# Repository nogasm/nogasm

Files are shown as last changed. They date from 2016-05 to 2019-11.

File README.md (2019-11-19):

# nogasm
Software and hardware for Arduino-based orgasm prediction / detection

### Case
The case can be 3D printed without support material. Print at least the top half of the case in white to see the LED display beneath. 

### PCB
All the Gerber files are included to order a set of PCBs. The [BOM is available on Octopart](https://octopart.com/bom-tool/FGy3gDRv). The PCB has mostly surface-mount components, and is doable with either a soldering iron or solder paste.

### Vibrator
The vibrator is made from a Mabuchi RS-555PH motor, with an eccentric mass pressed onto the shaft. These can be purchased pre-assembled, or built from the motor and some .88" to 1" diameter cylindrical brass stock.
The vibrator case is compatible with attachments designed for the Hitachi Magic Wand. The motor is press-fit or glued into the two halves of the case.

### Dependencies
This project uses a [Teensy LC](https://www.pjrc.com/store/teensylc.html), which will require the [teensyduino](https://www.pjrc.com/teensy/teensyduino.html) addon for the Arduino IDE, and its included [encoder library](https://github.com/PaulStoffregen/Encoder).
The detection algorithm uses a circular buffer for calculating a running average, [available here](https://github.com/RobTillaart/Arduino/tree/master/libraries/RunningAverage).

This work is licensed under a Creative Commons Attribution-NonCommercial 4.0 International Licence, available at http://creativecommons.org/licenses/by-nc/4.0/.

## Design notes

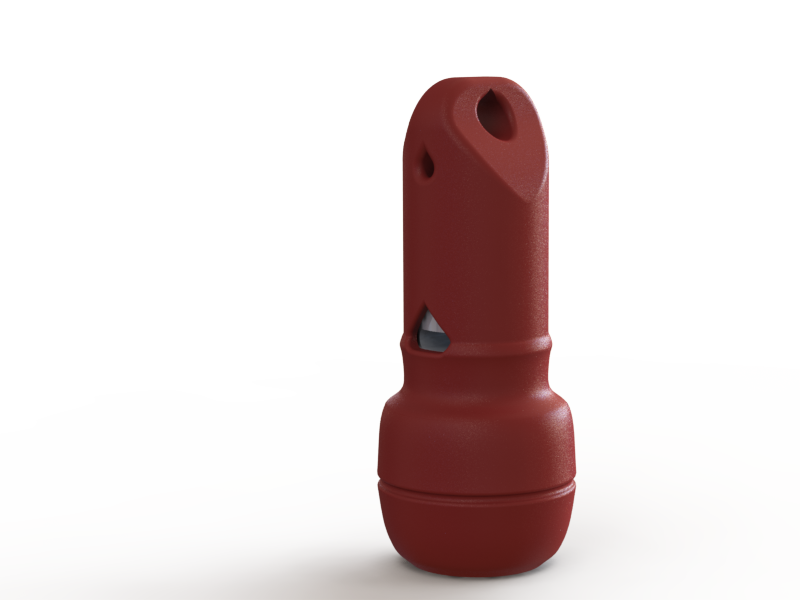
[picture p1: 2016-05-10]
vibrator/vibrator.png

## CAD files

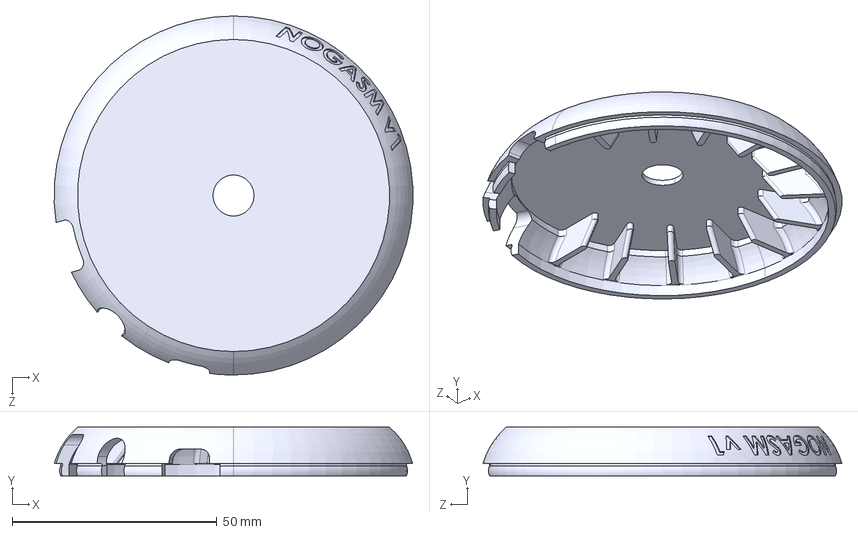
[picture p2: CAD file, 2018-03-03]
case/CaseUpper.STEP
87.5 x 11.9 x 87.6 mm

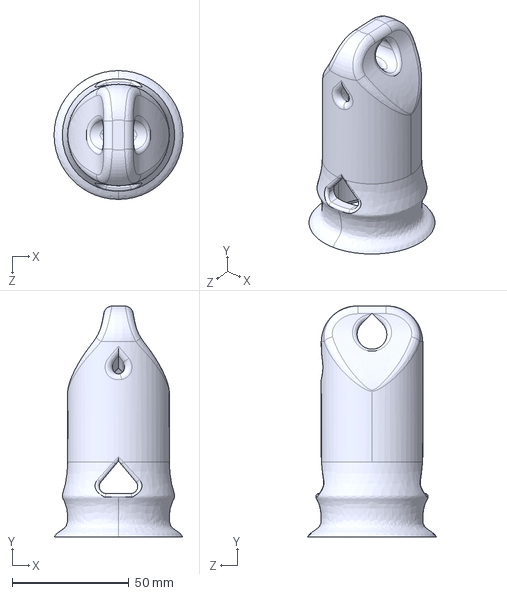
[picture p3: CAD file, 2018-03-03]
vibrator/handle.STEP
55.3 x 99.1 x 55.3 mm

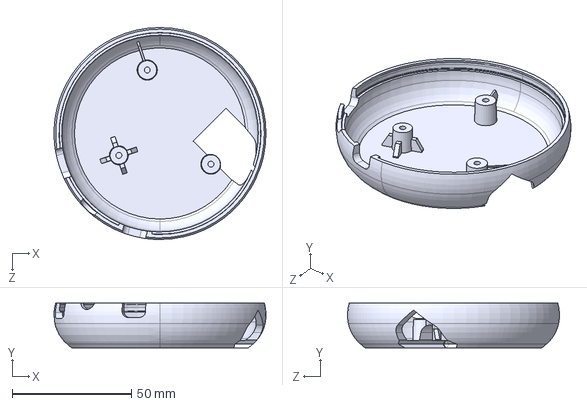
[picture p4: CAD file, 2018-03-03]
case/CaseLower.STEP
89.0 x 18.9 x 89.0 mm

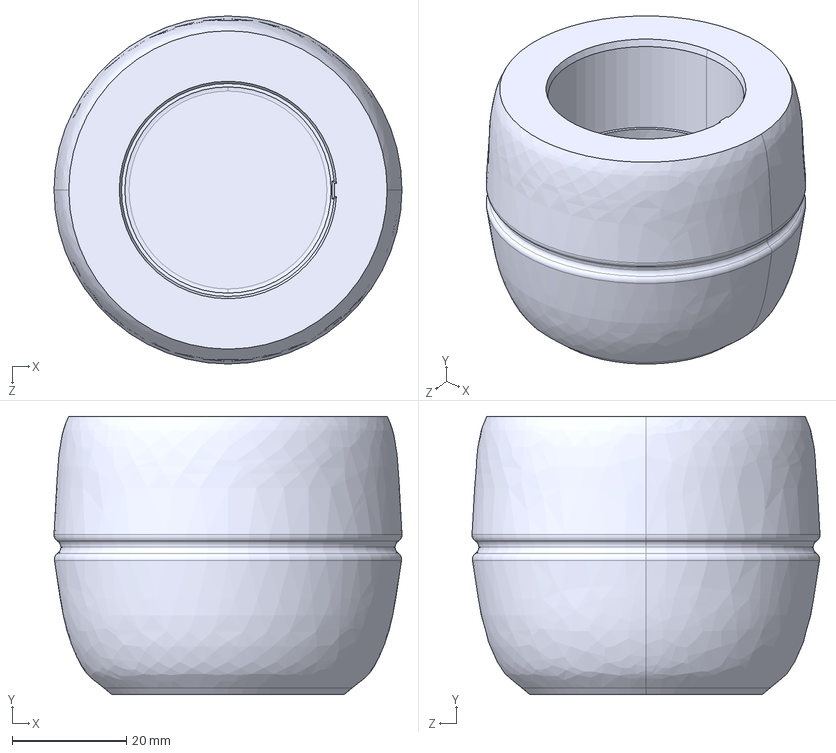
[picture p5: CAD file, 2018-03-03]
vibrator/head.STEP
60.8 x 48.6 x 60.8 mm

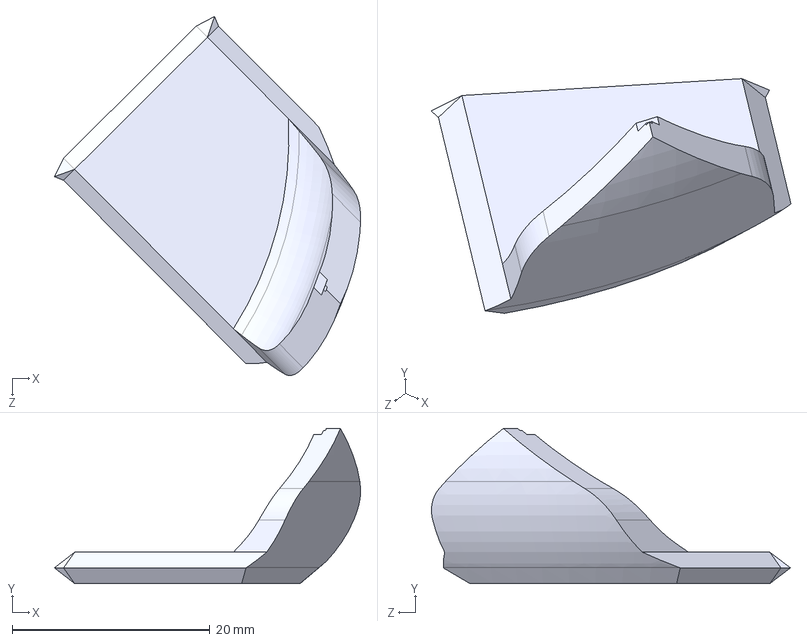
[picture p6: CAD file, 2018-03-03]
case/CaseProgramLid.STEP
31.0 x 15.7 x 36.3 mm

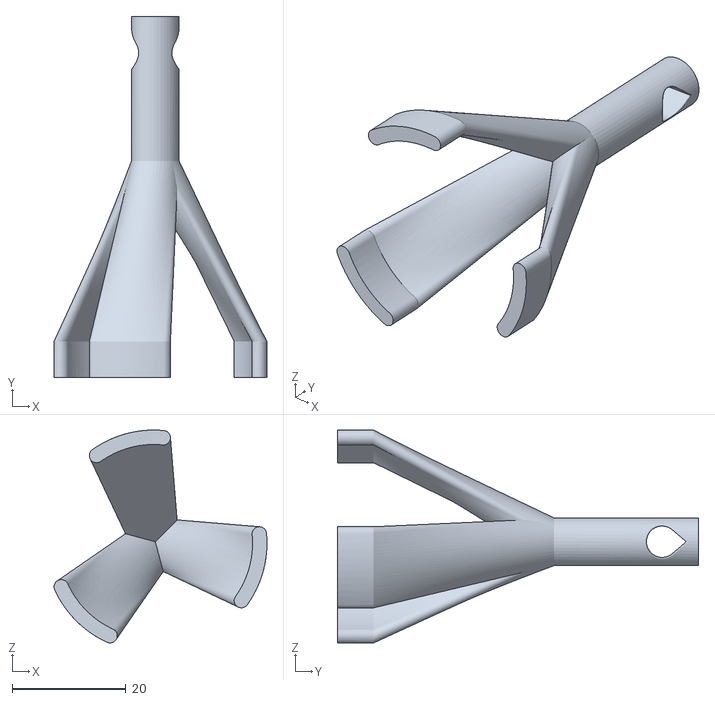
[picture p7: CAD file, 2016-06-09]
vibrator/finishing jig.STL
37.5 x 63.5 x 37.5

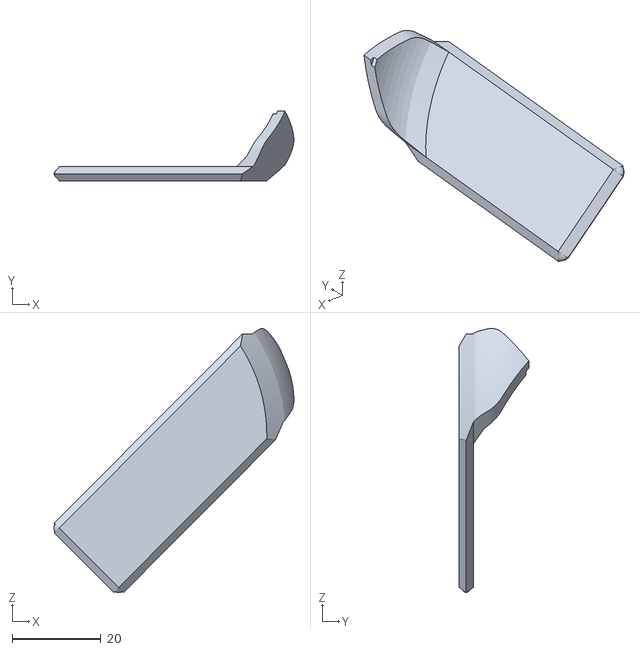
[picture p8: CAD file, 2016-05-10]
case/CaseLid.STL
54.1 x 15.7 x 59.6

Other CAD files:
case/CaseLower.STL
case/CaseUpper.STL
vibrator/handle.STL
vibrator/head.STL

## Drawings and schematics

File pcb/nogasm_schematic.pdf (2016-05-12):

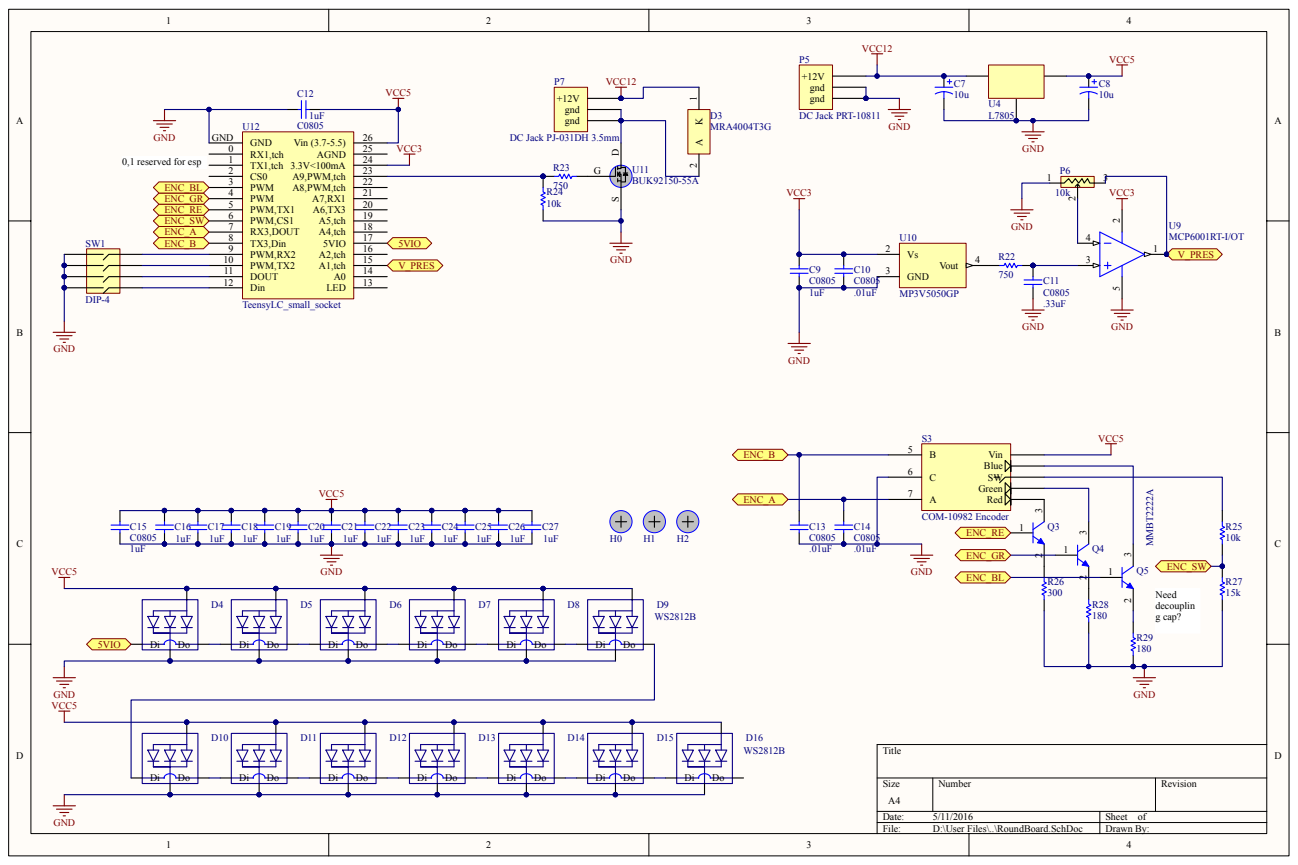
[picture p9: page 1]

Size A4 | Number | Revision

Date: 5/11/2016 | Sheet of
File: D:\User Files\..\RoundBoard.SchDoc | Drawn By:

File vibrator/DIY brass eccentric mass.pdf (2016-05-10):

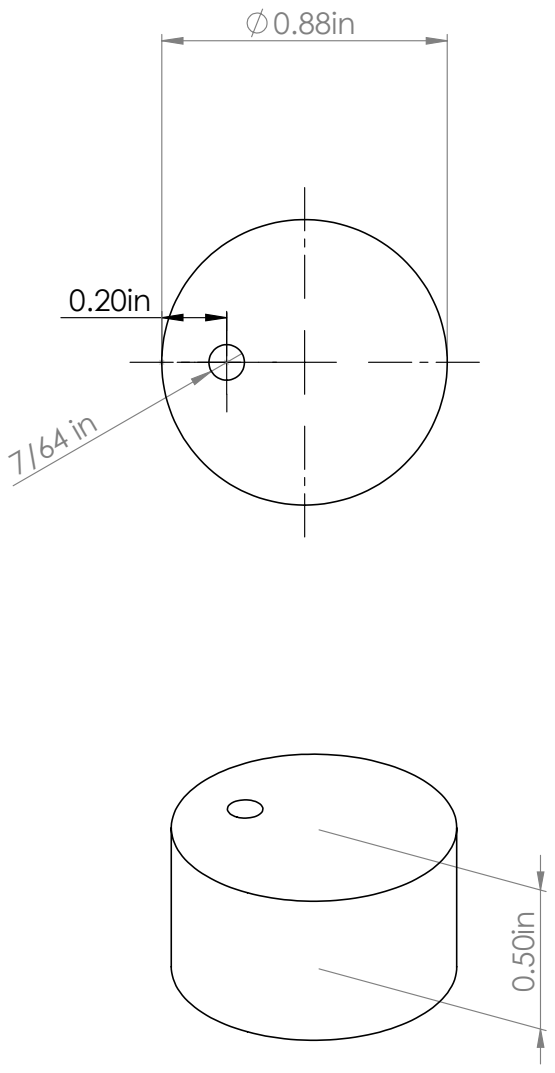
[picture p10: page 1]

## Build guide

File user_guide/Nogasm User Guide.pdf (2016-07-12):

## Nogasm User Guide

Basic Usage

1. Plug the motor into the right power jack.
2. Plug the power supply into the left power jack.
3. Fit the pressure tubing onto the barb fitting between the power jacks.
4. Connect an inflation bulb and inflatable butt plug to the pressure tubing as shown:

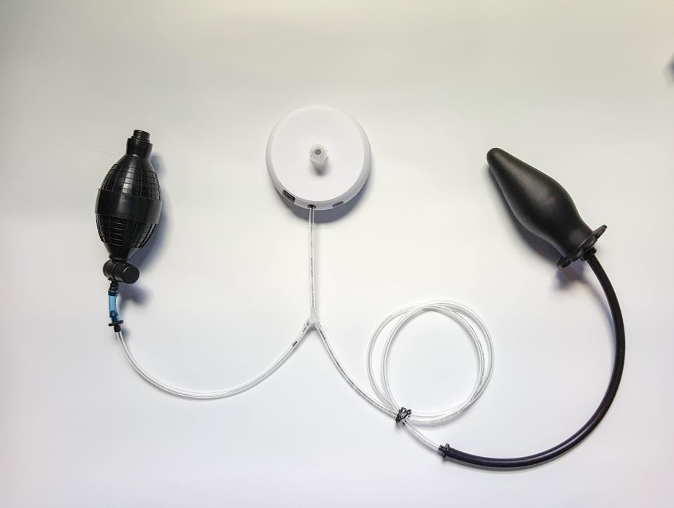
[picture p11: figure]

5. Nogasm detects approaching orgasms from pressure changes in an inflatable butt plug, so to use the edging feature, a user has to wear an at least slightly inflated plug.
6. Set up the vibrator for effective stimulation. Any common “Hitachi Magic Wand” attachment is compatible. If using rope to hold the vibrator in place, the loop in the back, and ridge behind the head of the vibrator can help keep it secure.
7. With the Nogasm on, turn the knob clockwise to check that the vibrator is working. Voluntarily clenching on the inflated plug should show some activity on the LED display at this point.
8. Press the knob once to enable the automated edging mode. The vibrator will slowly ramp up to its maximum speed.
9. The biggest key to a successful edging session is the edging sensitivity setting. Turn the knob clockwise to increase the sensitivity to maximum, and the display will turn from green to red, indicating that the user is too close to orgasm, and the vibrator will turn off temporarily.

10.From there, decrease the sensitivity slowly until you find the correct setting where the vibrator remains on just until the user is close to orgasm. Too high of a sensitivity will keep users from getting very close to orgasm at all, and too low of a sensitivity will allow the vibrator to stay on long enough for a user to cum. Ideal settings vary from person to person, and with different styles of inflatable plugs. If at any point a user is too close to orgasm, the knob can be pressed to immediately turn off the vibrator, and return to manual mode.
11.Finally, the included vibrator is relatively powerful, and lower speeds can feel better than 100% speed. To keep the vibrator at the best feeling speed in automatic mode, press the knob down for 1 second to enter the “Peak Speed” settings menu, which will change the display to all green. Rotating the knob will adjust the maximum speed that the edging mode will ramp up to, and drive the vibrator at that speed to demonstrate. By default, the maximum is set 70%. Long press one more time to return to manual mode.

Control

The Nogasm has one knob that can be rotated or pressed. Pressing the knob will change modes. Each mode illuminates the knob in a specific color, and uses the knob rotation to adjust different settings:

Mode | Knob Color | Knob rotation adjusts:
Manual | Red | Vibrator speed
Automatic Edging | Blue | Edging Sensitivity
Adjust Peak Speed | Green | Maximum vibrator speed in edging mode
Show Pressure Reading | White | [nothing]

Short presses cycle between manual control mode, and automatic edging mode. Long presses (between ½ and 3 seconds) enter the settings menu, which allows you to adjust the maximum speed the vibrator will ramp up to in automatic mode, or visualize raw pressure readings on the LEDs. A very long press (more than 3 seconds) will turn the device off until the knob is pressed again.

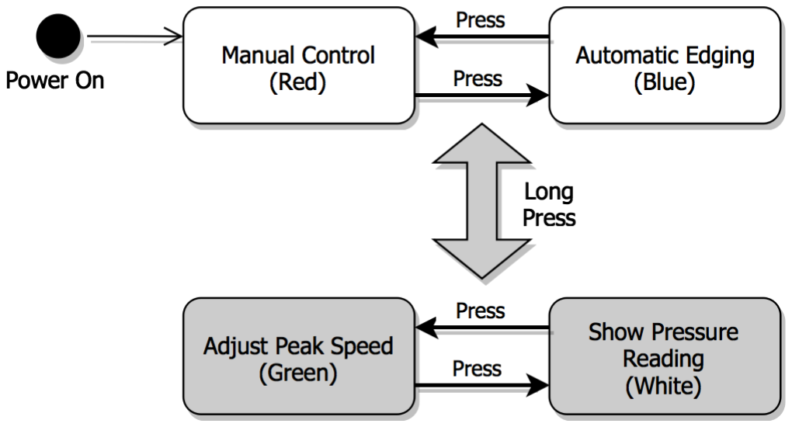
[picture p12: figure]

Troubleshooting

[The motor beeps out 3 high notes when an inflatable plug is inflated or squeezed]

- The 3-high note beep is a warning that the pressure from the inflatable plug is higher than the processor can read. Some plugs require more pressure to inflate, and will cause this issue. When the processor can’t read the pressure correctly, the automatic edging mode will not work.
- You can fix this problem by pulling off the knob and top cover of the Nogasm controller, and using a small screwdriver to manually adjust the pressure sensitivity.
- Turn the controller on, and hold the button down for 1 second to enter the motor speed adjustment menu (green), and then click the knob one time to enter the white “Show Pressure Reading” menu. The white graph directly shows the pressure read by the processor. When the pressure is high enough that the white point moves clockwise all the way to the right, the pressure reading is too high.
- Attach and inflate your plug the desired amount. If the white point now moves to or close to the right side of the controller, the pressure sensitivity should be reduced.
- Reduce the sensitivity by finding the small potentiometer dial, labeled P6 on the top of the circuit board. With a small flathead screwdriver, turn the dial counterclockwise until the lit white point moves near the middle of the scale (the top of the controller). When the plug is squeezed, the pressure should stay low enough that the white marker does not reach the right side of the controller, and the motor no longer beeps the warning code.

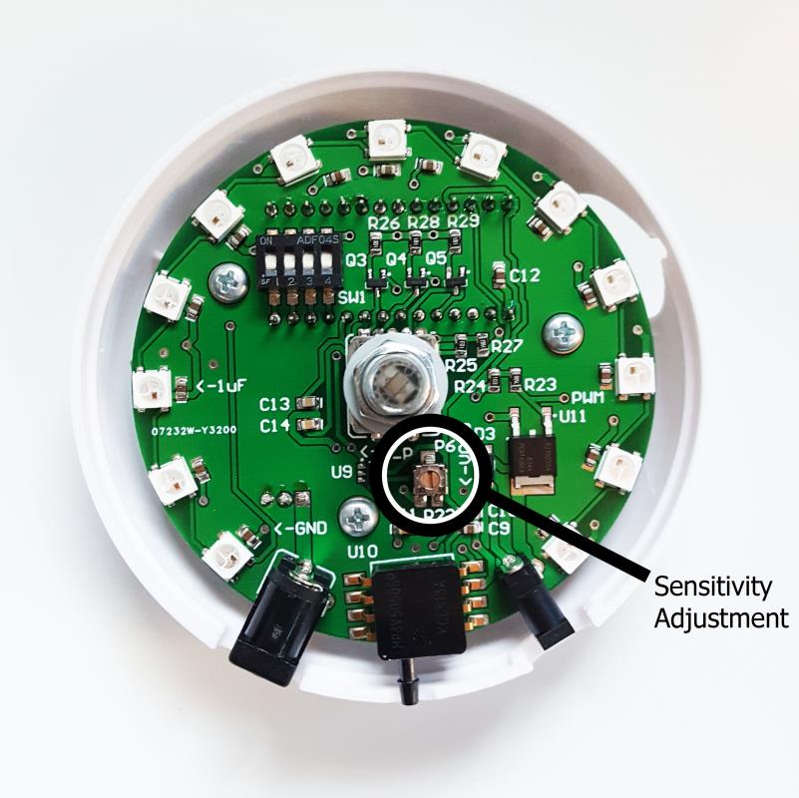
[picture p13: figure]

- The potentiometer adjusts the gain from the pressure sensor to the processor. Ideally, you want the gain (sensitivity) to be as high as it can without causing the 3 beep error. A higher gain makes it easier for the controller to detect orgasms.

Programming

Nogasm was designed to be easy to reprogram or hack for other fun uses. The simplest way to get started is to download the source code from github.com/nogasm/nogasm , and install the Arduino IDE with the Teensyduino add-on, to work with the Teensy-LC that runs Nogasm. The device can be reprogrammed via a Micro-USB cable after removing the programming lid on the bottom of the case.

The Github repository also includes circuit schematics, to make it easy to hack the board, or check if the existing circuitry, like if the 12V PWM motor driver is compatible with other hardware. With just software changes, you could drive a relay to control other toys instead of a vibrator, or even use the pressure sensor and some tubing to make a vibrating alarm clock that doesn’t turn off until it senses you’re out of bed.

USB Datalogging

By default, Nogasm reports its sensor readings and vibrator settings at 60 Hz over a USB virtual serial port at 115200 Baud. The format allows for direct logging to commaseparated variable (.csv) files, or easy visualization using the Arduino IDE’s built-in serial plotter. The format is as follows:

[Vibrator Speed],[Plug Pressure],[25-Second Average Pressure]

Where vibrator speed ranges from 0-255, and the pressures range from 0-4095.

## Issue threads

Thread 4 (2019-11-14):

Issue with Encoder not present in libraries

JB2989, 2019-11-14:
I 100% new to arduino so forgive my ignorance. I have uploaded the code and I get the error

"Arduino: 1.8.9 (Windows Store 1.8.21.0) (Windows 10), Board: "Arduino/Genuino Uno"

nogasm_code:45:21: error: Encoder.h: No such file or directory

compilation terminated.

exit status 1
Encoder.h: No such file or directory

This report would have more information with
"Show verbose output during compilation"
option enabled in File -> Preferences.

After further research. I am not able to locate the Libraries required for this code. Could you please add this online? Thank you

nogasm, 2019-11-19:
Sure thing. This uses a teensy LC, and in this case, encoder.h is one of great libraries written for that hardware, [available here.](https://github.com/PaulStoffregen/Encoder)

In the Arduino IDE, if you go to tools > include library > manage library and search "encoder" it will be one of the early results and is easiest to install there. You may first need the "teensyduino" addon installed, which you'll need for compilation anyway.

The other dependency you'll need is [Running Average, available here](https://github.com/RobTillaart/Arduino/tree/master/libraries/RunningAverage).

JB2989, 2019-11-19:
Thank you so much for this information! I probably have downloaded similar.. but incorect libraries. I'll give these a shot in the next day and hopefully have it working!

Very impressive work I may add!

Have a great day.

________________________________
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

nogasm, 2019-11-20:
No problem!

Closed 2019-11-20.

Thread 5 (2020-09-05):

PCB source

bat-of-fruit, 2020-09-05:
Hi, first thanks so much for bringing this into the world. Amazing. I'm building up the protogasm for testing, but would love to make something packaged a bit nicer like this. Would you be willing to share the source PCB design files and BoM?

headcrabned, 2020-09-20:
I (unwisely) made them in Altium when I had access to a license, and no longer do. I can share the files, but they're not generally very accessible without expensive software. Want to try anyway?
One other option is to try a fork in which someone recreated the board in KiCad, which is much more accessible: https://github.com/DunkelRatte/nogasm

nogasm, 2020-09-20:
That's a great request. I (unwisely) made them in Altium when I had access to a license, and no longer do. I can share the files, but they're not generally very accessible without expensive software. Want to try anyway?
One other option is to try a fork in which someone recreated the board in KiCad, which is much more accessible: https://github.com/DunkelRatte/nogasm

bat-of-fruit, 2020-09-22:
Thanks for pointing me to the kicad fork! Let me take a look at that first!
I wanted to mention, I’m part of a kinky makers group, I’d love to chat some more if you are up for it, we are bringing together people that are working on these types of projects for collaboration and idea sharing.

We have a discord if you’d like to drop by and say hello! A number of us have talked about extending nogasm functionality.

https://discord.gg/GJPcykr

gentlesartori, 2020-10-12:
Thanks! I have access to Altium through work so the files would still be
useful to me. Would you please send them?  many thanks!!

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

yorickdowne, 2021-03-30:
I looked at the KiCAD fork. It moves the mounting holes, which means adjusting the case in FreeCAD. While that can be done, would you share the Altium files? I'd like to run them through https://github.com/thesourcerer8/altium2kicad and see whether that works well. Maybe the original PCB can become a KiCAD project that way, and there's no need to redo the case.

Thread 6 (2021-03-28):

Case CAD source files

yorickdowne, 2021-03-28:
Would you / could you share the source CAD files for the case?

I noticed that the .STEP files are a newer version btw, for example the lid doesn't cut into the post any more. I have .STL generated from this, do you want a PR so .STL and .STEP reference the same design?

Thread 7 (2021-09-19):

Possibility of integration with buttplug.io (or similar api)

PointZero0, 2021-09-19:
I am interested in this codebase, especially in regards to control of teledildonic toys, and may want to integrate buttplug.io myself in my spare time. How accessible is the project to that kind of modification, and would this be something other people would also be interested in working on, as I don't have that much free time?

LanceLake, 2021-09-19:
The device doesn't really have a separate interface for the butt plug except to read the pressure of the air inside. If you can also come up with a new circuit to include stuff for it, then by all means, fork the code and go to town. :)

PointZero0, 2021-09-19:
Sorry for the confusion, the integration would be for the vibrator, not pressure-sensing, 'buttplug.io' is badly named, it is an interface to control remote toys. I highly doubt there exist other toys capable of reading pressure.

LanceLake, 2021-09-19:
Well, take a look at the code and yeah. If you feel you can improve on it, go ahead and make that fork.

Though I may be biased, I would fork from LanceLake/protogasm. I've went ahead and made the variables more clear and brought it up to a solid baseline adding in all the fixes from other branches. IMHO, it's the most up to date fork that I know about and hopefully, will be the direction of future forks.

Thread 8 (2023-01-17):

Need help checking my pcb setup. Teensy attached to it fried on 12v power, but motor didn't start (12v 5 Amp dc motor) 12v input. Tested on usb connection from computer and the pressure sensor seems to be working as does the encoder.

misticmight1, 2023-01-17:
On usb connection the rotary encoder and pressure sensor seemed to be working in serial plotter, but the motor did not move at all.
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

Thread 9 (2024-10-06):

Teensy LC EOL

heavyrubberslave, 2024-10-06:
I wanted to get my hands on this project but then realized that the Teensy LC is not available anymore. However from what I see the Teensy 4.0 is basically a drop-in replacement for the Teensy LC. It has the same pinouts in the through hole pins as the Teensy LC.
The only difference I can see is, that the Teensy 4.0 cannot handle 5V input on the pins compared to the Teensy LC. I checked the schema and from what I can tell (by far not an expert in reading schemas), there's no 5V input into the pins. Is this correct?

Has anybody successfully built the nogasm using the Teensy 4.0 instead of the Teensy LC?

Gollam, 2025-03-12:
@heavyrubberslave I was wondering about the same thing yesterday, but then fortunately I found a fork which uses a cheap arduino board, and moreover it does not require a PCB. Check it out: https://github.com/night-howler/protogasm

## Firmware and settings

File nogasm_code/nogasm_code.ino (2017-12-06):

// Jul 2016 - Nogasm Code Rev. 3
/* Drives a vibrator and uses changes in pressure of an inflatable buttplug
 * to estimate a user's closeness to orgasm, and turn off the vibrator
 * before that point.
 * A state machine updating at 60Hz creates different modes and option menus
 * that can be identified by the color of the LEDs, especially the RGB LED
 * in the central button/encoder knob.
 * 
 * [Red]    Manual Vibrator Control
 * [Blue]   Automatic vibrator edging, knob adjusts orgasm detection sensitivity
 * [Green]  Setting menu for maximum vibrator speed in automatic mode
 * [White]  Debubbing menu to show data from the pressure sensor ADC
 * [Off]    While still plugged in, holding the button down for >3 seconds turns
 *          the whole device off, until the button is pressed again.
 * 
 * Settings like edging sensitivity, or maximum motor speed are stored in EEPROM,
 * so they are saved through power-cycling.
 * 
 * In the automatic edging mode, the vibrator speed will linearly ramp up to full
 * speed (set in the green menu) over 30 seconds. If a near-orgasm is detected,
 * the vibrator abruptly turns off for 15 seconds, then begins ramping up again.
 * 
 * The motor will beep during power on/off, and if the plug pressure rises above
 * the maximum the board can read - this condition could lead to a missed orgasm 
 * if unchecked. The analog gain for the sensor is adjustable via a trimpot to
 * accomidate different types of plugs that have higher/lower resting pressures.
 * 
 * Motor speed, current pressure, and average pressure are reported via USB serial
 * at 115200 baud. Timestamps can also be enabled, from the main loop.
 * 
 * There is some framework for more features like an adjustable "cool off" time 
 * other than the default 15 seconds, and options for LED brightness and enabling/
 * disabling beeps. Four DIP switches are included on the board to allow users to
 * change other software settings without reflashing code. One example use would 
 * be switch 1 toggling between the defaul ramping motor behavior, and a strict
 * ON/OFF output to the motor that could instead be used to toggle a relay for 
 * driving other toys.
 * 
 * Note - Do not set all 13 LEDs to white at full brightness at once 
 * (RGB 255,255,255) It may overheat the voltage regulator and cause the board 
 * to reset.
 */
//=======Libraries===============================
#include <Encoder.h>
#include <EEPROM.h>
#include "FastLED.h"
#include "RunningAverage.h"

//=======Hardware Setup===============================
//LEDs
#define NUM_LEDS 13
#define LED_PIN 17 //5V buffered pin on Teensy LC, single wire data out to WS8212Bs
#define LED_TYPE    WS2812B
#define COLOR_ORDER GRB
#define BRIGHTNESS 255 //Subject to change, limits current that the LEDs draw

//Encoder
#define REDPIN   5 //RGB pins of the encoder LED
#define GREENPIN 4
#define BLUEPIN  3
#define ENC_SW   6 //Pushbutton on the encoder
Encoder myEnc(8, 7); //Quadrature inputs on pins 7,8

//DIP Switches
#define SW1PIN 12 //Dip switch pins, for setting software options without reflashing code
#define SW2PIN 11
#define SW3PIN 10
#define SW4PIN 9

//Motor
#define MOTPIN 23

//Pressure Sensor Analog In
#define BUTTPIN 15

//=======Software/Timing options=====================
#define FREQUENCY 60 //Update frequency in Hz
#define LONG_PRESS_MS 600 //ms requirements for a long press, to move to option menus
#define V_LONG_PRESS_MS 2500 //ms for a very long press, which turns the device off

//Update/render period
#define period (1000/FREQUENCY)
#define longBtnCount (LONG_PRESS_MS / period)

//Running pressure average array length and update frequency
#define RA_HIST_SECONDS 25
#define RA_FREQUENCY 6
#define RA_TICK_PERIOD (FREQUENCY / RA_FREQUENCY)
RunningAverage raPressure(RA_FREQUENCY*RA_HIST_SECONDS);
int sensitivity = 0; //orgasm detection sensitivity, persists through different states

//=======State Machine Modes=========================
#define MANUAL      1
#define AUTO        2
#define OPT_SPEED   3
#define OPT_RAMPSPD 4
#define OPT_BEEP    5
#define OPT_PRES    6


//Button states - no press, short press, long press
#define BTN_NONE   0
#define BTN_SHORT  1
#define BTN_LONG   2
#define BTN_V_LONG 3


uint8_t state = MANUAL;
//=======Global Settings=============================
//DIP switch options:
uint8_t MOT_MAX =   179; //By default, motor speed only ever reaches 179. Alternative is 255
bool SW2 =        false;
bool SW3 =        false;
bool SW4 =        false;
#define MOT_MIN 20  // Motor PWM minimum.  It needs a little more than this to start.

CRGB leds[NUM_LEDS];

int pressure = 0;
int avgPressure = 0; //Running 25 second average pressure
//int bri =100; //Brightness setting
int rampTimeS = 30; //Ramp-up time, in seconds
#define DEFAULT_PLIMIT 600
int pLimit = DEFAULT_PLIMIT; //Limit in change of pressure before the vibrator turns off
int maxSpeed = 255; //maximum speed the motor will ramp up to in automatic mode
float motSpeed = 0; //Motor speed, 0-255 (float to maintain smooth ramping to low speeds)

//=======EEPROM Addresses============================
//128b available on teensy LC
#define BEEP_ADDR         1
#define MAX_SPEED_ADDR    2
#define SENSITIVITY_ADDR  3
//#define RAMPSPEED_ADDR    4 //For now, ramp speed adjustments aren't implemented

//=======Setup=======================================
//Beep out tones over the motor by frequency (1047,1396,2093) may work well
void beep_motor(int f1, int f2, int f3){
  if(motSpeed > 245) analogWrite(MOTPIN, 245); //make sure the frequency is audible
  else if(motSpeed < 10) analogWrite(MOTPIN, 10);
  analogWriteFrequency(MOTPIN, f1);
  delay(250);
  analogWriteFrequency(MOTPIN, f2);
  delay(250);
  analogWriteFrequency(MOTPIN, f3);
  delay(250);
  analogWriteFrequency(MOTPIN, 440);
  analogWrite(MOTPIN,motSpeed);
}

void setup() {
  pinMode(REDPIN,   OUTPUT); //Connected to RGB LED in the encoder
  pinMode(GREENPIN, OUTPUT);
  pinMode(BLUEPIN,  OUTPUT);
  pinMode(ENC_SW,   INPUT); //Pin to read quadrature pulses from encoder

  pinMode(SW1PIN,   INPUT); //Set DIP switch pins as inputs
  pinMode(SW2PIN,   INPUT);
  pinMode(SW3PIN,   INPUT);
  pinMode(SW4PIN,   INPUT);

  digitalWrite(SW1PIN, HIGH); //Enable pullup resistors on DIP switch pins.
  digitalWrite(SW2PIN, HIGH); //They are tied to GND when switched on.
  digitalWrite(SW3PIN, HIGH);
  digitalWrite(SW4PIN, HIGH);

  pinMode(MOTPIN,OUTPUT); //Enable "analog" out (PWM)
  
  pinMode(BUTTPIN,INPUT); //default is 10 bit resolution (1024), 0-3.3
  analogReadRes(12); //changing ADC resolution to 12 bits (4095)
  analogReadAveraging(32); //To reduce noise, average 32 samples each read.
  
  raPressure.clear(); //Initialize a running pressure average

  digitalWrite(MOTPIN, LOW);//Make sure the motor is off

  delay(3000); // 3 second delay for recovery

  //If a pin reads low, the switch is enabled. Here, we read in the DIP settings
  //Right now, only SW1 is used, for enabling higher maximum motor speed.
  if(digitalRead(SW1PIN)){
    MOT_MAX = 179; //At the default low position, limit the motor speed
  }
  else{
    MOT_MAX = 255; //When SW1 is flipped high, allow higher motor speeds
  }
  SW2 = (digitalRead(SW2PIN) == LOW);
  SW3 = (digitalRead(SW3PIN) == LOW);
  SW4 = (digitalRead(SW4PIN) == LOW);

  Serial.begin(115200);

  FastLED.addLeds<LED_TYPE, LED_PIN, COLOR_ORDER>(leds, NUM_LEDS).setCorrection(TypicalLEDStrip);
  // limit power draw to .6A at 5v... Didn't seem to work in my FastLED version though
  //FastLED.setMaxPowerInVoltsAndMilliamps(5,DEFAULT_PLIMIT);
  FastLED.setBrightness(BRIGHTNESS);

  //Recall saved settings from memory
  sensitivity = EEPROM.read(SENSITIVITY_ADDR);
  maxSpeed = min(EEPROM.read(MAX_SPEED_ADDR),MOT_MAX); //Obey the MOT_MAX the first power  cycle after chaning it.
  beep_motor(1047,1396,2093); //Power on beep
}

//=======LED Drawing Functions=================

void showKnobRGB(const CRGB& rgb)
{
  analogWrite(REDPIN,   rgb.r );
  analogWrite(GREENPIN, rgb.g );
  analogWrite(BLUEPIN,  rgb.b );
}

//Draw a "cursor", one pixel representing either a pressure or encoder position value
//C1,C2,C3 are colors for each of 3 revolutions over the 13 LEDs (39 values)
void draw_cursor_3(int pos,CRGB C1, CRGB C2, CRGB C3){
  pos = constrain(pos,0,NUM_LEDS*3-1);
  int colorNum = pos/NUM_LEDS; //revolution number
  int cursorPos = pos % NUM_LEDS; //place on circle, from 0-12
  switch(colorNum){
    case 0:
      leds[cursorPos] = C1;
      break;
    case 1:
      leds[cursorPos] = C2;
      break;
    case 2:
      leds[cursorPos] = C3;
      break;
  }
}

//Draw a "cursor", one pixel representing either a pressure or encoder position value
void draw_cursor(int pos,CRGB C1){
  pos = constrain(pos,0,NUM_LEDS-1);
  leds[pos] = C1;
}

//Draw 3 revolutions of bars around the LEDs. From 0-39, 3 colors
void draw_bars_3(int pos,CRGB C1, CRGB C2, CRGB C3){
  pos = constrain(pos,0,NUM_LEDS*3-1);
  int colorNum = pos/NUM_LEDS; //revolution number
  int barPos = pos % NUM_LEDS; //place on circle, from 0-12
  switch(colorNum){
    case 0:
      fill_gradient_RGB(leds,0,C1,barPos,C1);
      //leds[barPos] = C1;
      break;
    case 1:
      fill_gradient_RGB(leds,0,C1,barPos,C2);
      break;
    case 2:
      fill_gradient_RGB(leds,0,C2,barPos,C3);
      break;
  }
}

//Provide a limited encoder reading corresponting to tacticle clicks on the knob.
//Each click passes through 4 encoder pulses. This reduces it to 1 pulse per click
int encLimitRead(int minVal, int maxVal){
  if(myEnc.read()>maxVal*4)myEnc.write(maxVal*4);
  else if(myEnc.read()<minVal*4) myEnc.write(minVal*4);
  return constrain(myEnc.read()/4,minVal,maxVal);
}

//=======Program Modes/States==================

// Manual vibrator control mode (red), still shows orgasm closeness in background
void run_manual() {
  //In manual mode, only allow for 13 cursor positions, for adjusting motor speed.
  int knob = encLimitRead(0,12);
  motSpeed = map(knob, 0, 12, 0., (float)MOT_MAX);
  analogWrite(MOTPIN, motSpeed);

  //gyrGraphDraw(avgPressure, 0, 4 * 3 * NUM_LEDS);
  int presDraw = map(constrain(pressure - avgPressure, 0, pLimit),0,pLimit,0,NUM_LEDS*3);
  draw_bars_3(presDraw, CRGB::Green,CRGB::Yellow,CRGB::Red);
  draw_cursor(knob, CRGB::Red);
}

// Automatic edging mode, knob adjust sensitivity.
void run_auto() {
  static float motIncrement = 0.0;
  motIncrement = ((float)maxSpeed / ((float)FREQUENCY * (float)rampTimeS));

  int knob = encLimitRead(0,(3*NUM_LEDS)-1);
  sensitivity = knob*4; //Save the setting if we leave and return to this state
  //Reverse "Knob" to map it onto a pressure limit, so that it effectively adjusts sensitivity
  pLimit = map(knob, 0, 3 * (NUM_LEDS - 1), 600, 1); //set the limit of delta pressure before the vibrator turns off
  //When someone clenches harder than the pressure limit
  if (pressure - avgPressure > pLimit) {
    motSpeed = -.5*(float)rampTimeS*((float)FREQUENCY*motIncrement);//Stay off for a while (half the ramp up time)
  }
  else if (motSpeed < (float)maxSpeed) {
    motSpeed += motIncrement;
  }
  if (motSpeed > MOT_MIN) {
    analogWrite(MOTPIN, (int) motSpeed);
  } else {
    analogWrite(MOTPIN, 0);
  }

  int presDraw = map(constrain(pressure - avgPressure, 0, pLimit),0,pLimit,0,NUM_LEDS*3);
  draw_bars_3(presDraw, CRGB::Green,CRGB::Yellow,CRGB::Red);
  draw_cursor_3(knob, CRGB(50,50,200),CRGB::Blue,CRGB::Purple);

}

//Setting menu for adjusting the maximum vibrator speed automatic mode will ramp up to
void run_opt_speed() {
  Serial.println("speed settings");
  int knob = encLimitRead(0,12);
  motSpeed = map(knob, 0, 12, 0., (float)MOT_MAX);
  analogWrite(MOTPIN, motSpeed);
  maxSpeed = motSpeed; //Set the maximum ramp-up speed in automatic mode
  //Little animation to show ramping up on the LEDs
  static int visRamp = 0;
  if(visRamp <= FREQUENCY*NUM_LEDS-1) visRamp += 16;
  else visRamp = 0;
  draw_bars_3(map(visRamp,0,(NUM_LEDS-1)*FREQUENCY,0,knob),CRGB::Green,CRGB::Green,CRGB::Green);
}

//Not yet added, but adjusts how quickly the vibrator turns back on after being triggered off
void run_opt_rampspd() {
  Serial.println("rampSpeed");
}

//Also not completed, option for enabling/disabling beeps
void run_opt_beep() {
  Serial.println("Brightness Settings");
}

//Simply display the pressure analog voltage. Useful for debugging sensitivity issues.
void run_opt_pres() {
  int p = map(analogRead(BUTTPIN),0,4095,0,NUM_LEDS-1);
  draw_cursor(p,CRGB::White);
}

//Poll the knob click button, and check for long/very long presses as well
uint8_t check_button(){
  static bool lastBtn = LOW;
  static unsigned long keyDownTime = 0;
  uint8_t btnState = BTN_NONE;
  bool thisBtn = digitalRead(ENC_SW);

  //Detect single presses, no repeating, on keyup
  if(thisBtn == HIGH && lastBtn == LOW){
    keyDownTime = millis();
  }
  
  if (thisBtn == LOW && lastBtn == HIGH) { //there was a keyup
    if((millis()-keyDownTime) >= V_LONG_PRESS_MS){
      btnState = BTN_V_LONG;
    }
    else if((millis()-keyDownTime) >= LONG_PRESS_MS){
      btnState = BTN_LONG;
      }
    else{
      btnState = BTN_SHORT;
      }
    }

  lastBtn = thisBtn;
  return btnState;
}

//run the important/unique parts of each state. Also, set button LED color.
void run_state_machine(uint8_t state){
  switch (state) {
      case MANUAL:
        showKnobRGB(CRGB::Red);
        run_manual();
        break;
      case AUTO:
        showKnobRGB(CRGB::Blue);
        run_auto();
        break;
      case OPT_SPEED:
        showKnobRGB(CRGB::Green);
        run_opt_speed();
        break;
      case OPT_RAMPSPD:
        showKnobRGB(CRGB::Yellow);
        run_opt_rampspd();
        break;
      case OPT_BEEP:
        showKnobRGB(CRGB::Purple);
        run_opt_beep();
        break;
      case OPT_PRES:
        showKnobRGB(CRGB::White);
        run_opt_pres();
        break;
      default:
        run_manual();
        break;
    }
}

//Switch between state machine states, and reset the encoder position as necessary
//Returns the next state to run. Very long presses will turn the system off (sort of)
uint8_t set_state(uint8_t btnState, uint8_t state){
  if(btnState == BTN_NONE){
    return state;
  }
  if(btnState == BTN_V_LONG){
    //Turn the device off until woken up by the button
    Serial.println("power off");
    fill_gradient_RGB(leds,0,CRGB::Black,NUM_LEDS-1,CRGB::Black);//Turn off LEDS
    FastLED.show();
    showKnobRGB(CRGB::Black);
    analogWrite(MOTPIN, 0);
    beep_motor(2093,1396,1047);
    analogWrite(MOTPIN, 0); //Turn Motor off
    while(!digitalRead(ENC_SW))delay(1);
    beep_motor(1047,1396,2093);
    return MANUAL ;
  }
  else if(btnState == BTN_SHORT){
    switch(state){
      case MANUAL:
        myEnc.write(sensitivity);//Whenever going into auto mode, keep the last sensitivity
        motSpeed = 0; //Also reset the motor speed to 0
        return AUTO;
      case AUTO:
        myEnc.write(0);//Whenever going into manual mode, set the speed to 0.
        motSpeed = 0;
        EEPROM.update(SENSITIVITY_ADDR, sensitivity);
        return MANUAL;
      case OPT_SPEED:
        myEnc.write(0);
        EEPROM.update(MAX_SPEED_ADDR, maxSpeed);
        //return OPT_RAMPSPD;
        //return OPT_BEEP;
        motSpeed = 0;
        analogWrite(MOTPIN, motSpeed); //Turn the motor off for the white pressure monitoring mode
        return OPT_PRES; //Skip beep and rampspeed settings for now
      case OPT_RAMPSPD: //Not yet implimented
        //motSpeed = 0;
        //myEnc.write(0);
        return OPT_BEEP;
      case OPT_BEEP:
        myEnc.write(0);
        return OPT_PRES;
      case OPT_PRES:
        myEnc.write(map(maxSpeed,0,255,0,4*(NUM_LEDS)));//start at saved value
        return OPT_SPEED;
    }
  }
  else if(btnState == BTN_LONG){
    switch (state) {
          case MANUAL:
            myEnc.write(map(maxSpeed,0,255,0,4*(NUM_LEDS)));//start at saved value
            return OPT_SPEED;
          case AUTO:
            myEnc.write(map(maxSpeed,0,255,0,4*(NUM_LEDS)));//start at saved value
            return OPT_SPEED;
          case OPT_SPEED:
            myEnc.write(0);
            return MANUAL;
          case OPT_RAMPSPD:
            return MANUAL;
          case OPT_BEEP:
            return MANUAL;
          case OPT_PRES:
            myEnc.write(0);
            return MANUAL;
        }
  }
  else return MANUAL;
}

//=======Main Loop=============================
void loop() {
  static uint8_t state = MANUAL;
  static int sampleTick = 0;
  //Run this section at the update frequency (default 60 Hz)
  if (millis() % period == 0) {
    delay(1);
    
    sampleTick++; //Add pressure samples to the running average slower than 60Hz
    if (sampleTick % RA_TICK_PERIOD == 0) {
      raPressure.addValue(pressure);
      avgPressure = raPressure.getAverage();
    }
    
    pressure = analogRead(BUTTPIN);
    fadeToBlackBy(leds,NUM_LEDS,20); //Create a fading light effect. LED buffer is not otherwise cleared
    uint8_t btnState = check_button();
    state = set_state(btnState,state); //Set the next state based on this state and button presses
    run_state_machine(state);
    FastLED.show(); //Update the physical LEDs to match the buffer in software

    //Alert that the Pressure voltage amplifier is railing, and the trim pot needs to be adjusted
    if(pressure > 4030)beep_motor(2093,2093,2093); //Three high beeps

    //Report pressure and motor data over USB for analysis / other uses. timestamps disabled by default
    //Serial.print(millis()); //Timestamp (ms)
    //Serial.print(",");
    Serial.print(motSpeed); //Motor speed (0-255)
    Serial.print(",");
    Serial.print(pressure); //(Original ADC value - 12 bits, 0-4095)
    Serial.print(",");
    Serial.println(avgPressure); //Running average of (default last 25 seconds) pressure

  }
}

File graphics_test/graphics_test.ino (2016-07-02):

// Feb 2016 - Graphics Test
//=======Libraries===============================
#include <Encoder.h>
#include "FastLED.h"
#include "RunningAverage.h"

//=======Hardware Setup===============================
//LEDs
#define NUM_LEDS 13
#define LED_PIN 17 //5V buffered pin on Teensy LC, single wire data out to WS8212Bs
#define LED_TYPE    WS2812B
#define COLOR_ORDER GRB
#define BRIGHTNESS 255 //Subject to change, limits current that the LEDs draw

//Encoder
#define REDPIN   5 //RGB pins of the encoder LED
#define GREENPIN 4
#define BLUEPIN  3
#define ENC_SW   6 //Pushbutton on the encoder
Encoder myEnc(8, 7); //Quadrature inputs on pins 7,8

//DIP Switches
#define SW1PIN 12 //Dip switch pins, for setting software options without reflashing code
#define SW2PIN 11
#define SW3PIN 10
#define SW4PIN 9

//Motor
#define MOTPIN 23

//Pressure Sensor Analog In
#define BUTTPIN 15

//=======Software/Timing options=====================
#define FREQUENCY 60 //Update frequency in Hz
#define LONG_PRESS_MS 2000 //ms requirements for a long press

//Update/render period
#define period (1000/FREQUENCY)
#define longBtnCount (LONG_PRESS_MS / period)

//Running pressure average array length and update frequency
#define RA_HIST_SECONDS 25
#define RA_FREQUENCY 6
#define RA_TICK_PERIOD (FREQUENCY / RA_FREQUENCY)
RunningAverage raPressure(RA_FREQUENCY*RA_HIST_SECONDS);

//=======State Machine Modes=========================
#define MANUAL      1
#define AUTO        2
#define OPT_SPEED   3
#define OPT_RAMPSPD 4
#define OPT_BEEP    5
#define OPT_PRES    6
#define SAVE        7
#define RESET       8

uint8_t state = MANUAL;
//=======Global Variables=============================
//DIP switch options:
bool SERIAL_EN =  false;
bool SW2 =        false;
bool SW3 =        false;
bool SW4 =        false;

CRGB leds[NUM_LEDS];
int cursorLed = 0;

int oldEnc = 0; //previously observed encoder position
int newEnc = 0;
int encPos = 0;
bool btnPress = 0;
int longPress = 0;
int pressure = 0;
int avgPressure = 0;
int bri =100;
const int pOffset = analogRead(BUTTPIN);
int rampTimeS = 30;
int pLimit = 300;
//=======Setup=======================================
void setup() {
  pinMode(REDPIN,   OUTPUT);
  pinMode(GREENPIN, OUTPUT);
  pinMode(BLUEPIN,  OUTPUT);
  pinMode(ENC_SW,   INPUT);

  //Set DIP switch pins as inputs
  pinMode(SW1PIN,   INPUT);
  pinMode(SW2PIN,   INPUT);
  pinMode(SW3PIN,   INPUT);
  pinMode(SW4PIN,   INPUT);

  //Enable pullup resistors on DIP pins. They are tied to GND if enabled.
  digitalWrite(SW1PIN, HIGH);
  digitalWrite(SW2PIN, HIGH);
  digitalWrite(SW3PIN, HIGH);
  digitalWrite(SW4PIN, HIGH);

  pinMode(MOTPIN,   OUTPUT); //Might want uh, analog out? PWM at some frequency.
  pinMode(BUTTPIN,  INPUT);
  raPressure.clear(); //Initialize a running pressure average
  //Make sure the motor is off
  digitalWrite(MOTPIN, LOW);

  delay(3000); // 3 second delay for recovery

  //If a pin reads low, the switch is enabled. Here, we read in the DIP settings
  //Right now, only SW1 is used, for en/disabling serial.
  SERIAL_EN = (digitalRead(SW1PIN) == LOW);
  SW2 = (digitalRead(SW2PIN) == LOW);
  SW3 = (digitalRead(SW3PIN) == LOW);
  SW4 = (digitalRead(SW4PIN) == LOW);

  if (SERIAL_EN) {
    Serial.begin(115200);
  }

  FastLED.addLeds<LED_TYPE, LED_PIN, COLOR_ORDER>(leds, NUM_LEDS).setCorrection(TypicalLEDStrip);
  // limit my draw to .6A at 5v of power draw
  //FastLED.setMaxPowerInVoltsAndMilliamps(5,600);
  FastLED.setBrightness(BRIGHTNESS);
}

//=======LED Drawing Functions=================


//Fade all LEDs to 200/255 their previous value
void fadeall() {
  for (int i = 0; i < NUM_LEDS; i++) {
    leds[i].nscale8(245);
  }
}

void showAnalogRGB(const CRGB& rgb)
{
  analogWrite(REDPIN,   rgb.r );
  analogWrite(GREENPIN, rgb.g );
  analogWrite(BLUEPIN,  rgb.b );
}

void draw_cursor(int pos,CRGB C1, CRGB C2, CRGB C3){
  pos = constrain(pos,1,NUM_LEDS*3);
  int colorNum = pos/NUM_LEDS;
  int cursorPos = pos % NUM_LEDS;
  switch(colorNum){
    case 0:
      leds[cursorPos] = C1;
      break;
    case 1:
      leds[cursorPos] = C2;
      break;
    case 2:
      leds[cursorPos] = C3;
      break;
  }
}

void draw_bars(int pos,CRGB C1, CRGB C2, CRGB C3){
  pos = constrain(pos,1,NUM_LEDS*3);
  int colorNum = pos/NUM_LEDS;
  int barPos = pos % NUM_LEDS;
  switch(colorNum){
    case 0:
      //fill_solid(leds, NUM_LEDS, CHSV(0,0,0)); //black background
      //fill_solid(leds, barPos, C1);
      leds[barPos] = C1;
      break;
    case 1:
      //fill_solid(leds, NUM_LEDS, C1);
      //fill_solid(leds, barPos, C2);
      leds[barPos] = C2;
      break;
    case 2:
      //fill_solid(leds, NUM_LEDS, C2);
      //fill_solid(leds, barPos, C3);
      leds[barPos] = C3;
      break;
  }
}

//Bleep out over the motor (1047,1396,2093) may work well
void beep_motor(int f1, int f2, int f3){
  analogWrite(MOTPIN, 10); //Some value low enough so that the motor does not spin
  analogWriteFrequency(MOTPIN, f1);
  delay(250);
  analogWriteFrequency(MOTPIN, f2);
  delay(250);
  analogWriteFrequency(MOTPIN, f3);
  delay(250);
}
int pos = 0;
//=======Main Loop=============================
void loop() {
  //Run everything at the update frequency
  if (millis() % period == 0) {
    //Serial.print(state);
    delay(1);
    
    pos = myEnc.read();
    CRGB red = CRGB::Red;
    CRGB green = CRGB::Green;
    CRGB yellow = CRGB::Yellow;
    CRGB purple = CRGB::Purple;

    //leds[pos/4] = green;
    fadeToBlackBy(leds,NUM_LEDS,20);
    
    
    FastLED.show();
    //beep_motor(1047,1396,2093);
    //delay(1000);
  }
  pressure = analogRead(BUTTPIN) - pOffset;
  draw_cursor(pos/4,CRGB::LightBlue,CRGB::Blue,CRGB::Purple);
  draw_cursor(pressure,CRGB::Green,CRGB::Yellow,CRGB::Red);






}

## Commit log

2016-05-10 Added case and vibrator stl models
    [CaseLid.STL, CaseLower.STL, CaseUpper.STL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]
2016-05-11 Added very rough arduino code for hardware tests
2016-05-12 Uploaded schematic
2016-05-12 Added motor beep function
2016-05-21 STL Improvements
    In case STL, added logo, increased resolution, reduced tolerance between
    parts for tighter fit.
    [CaseLower.STL, CaseUpper.STL]
2016-06-09 Vibrator update
    Reduced clearance for the motor press fit, added features to prevent
    motor rotation or translation
    [finishing jig.STL, handle.STL, head.STL]
2016-07-02 Big update to the nogasm code, many new features
    Added fading LED effect, restructured some code, added new menus and
    options for setting motor speed, settings are now saved in EEPROM.
2016-07-02 Beeping bugfix
    fixed issue where the motor would turn on in the white pressure
    monitoring mode
    [nogasm_code.ino]
2016-08-05 Max motor speed is settable by DIP switch
    Previously, the maximum vibrator motor speed was 100% duty cycle (255).
    This was in most cases too high for comfort. The maximum motor speed is
    now 70%. However, the original 100% can still be unlocked by switching
    on DIP 1 on the PCB.
    [nogasm_code.ino]
2017-08-02 Added PCB Gerbers
    [RoundPCB.GBL, RoundPCB.GBO, RoundPCB.GBS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]
2017-12-05 Bugfix: don't underflow motor speed
    The Teensy LC libraries floor analogWrite at 0. Standard Arduino
    libraries wrap around when it underflows instead, resulting in the motor
    running when it shouldn't. Fix it.
    This also adds a minimum speed for the motor to prevent it from trying
    to start until it plausibly can.
    [nogasm_code.ino]
2018-03-03 Added .STEP mechanical files for easier modification
    STEP files for the vibrator and project case added next to the .STLs
    [CaseLower.STEP, CaseProgramLid.STEP, CaseUpper.STEP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]
